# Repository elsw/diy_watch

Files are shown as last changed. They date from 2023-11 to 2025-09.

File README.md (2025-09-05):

# binary_watch

This is a project to create a homecrew binary watch to fit inside a analogue wrist watch

## issues

- No Vcc out of the LTC4071 chip, swapped LBSEL to set the `Low Battery Connect` to 3.6V but never get any voltage out. Change to MCP73833? also cheaper. [reference curcuit](https://learn.adafruit.com/li-ion-and-lipoly-batteries/downloads)
- Cannot debug RP2040 code, got it working once but not again, I think it's something up with the cdoe itself, debugging reliable blink code though... (change to pico 2??) (try embassy???)

## TODO

- Swap battery charger for MCP73833
- Recreate breadboard setup, test in rust
- Change PCB to 4 layer
- Change programming port for 3 pin JST SH (pico probe standard)
- Romove bool sel switch in favour of solder pads
- Swap LIR battery with space for lipo
- Add charging state LED

## Components
```
Cheap 6 digit LCD display
Raspberry Pi RP2040 Microchip
150mah lipo - https://thepihut.com/products/150mah-3-7v-lipo-battery
DS3231 real time clock
charging chip (breakout https://www.adafruit.com/product/259)
Standarise programming port on pico probe wire (1mm JST-SH, SM03B-SRSS-TB)
```

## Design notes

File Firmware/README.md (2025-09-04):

# DIY Watch firmware

This is the firmware for the DIY watch to run the raspberry pi RP2040 microcontroller

## References

[RP2040 Datasheet](https://datasheets.raspberrypi.com/rp2040/rp2040-datasheet.pdf)
[Raspberry Pi Pico C/C++ SDK](https://datasheets.raspberrypi.com/pico/raspberry-pi-pico-c-sdk.pdf)
[Driving multiplexed LCD directly](https://ww1.microchip.com/downloads/en/Appnotes/doc8103.pdf)

# Windows Setup

Install VS code and install the pico extension. Import this folder using the pico import tool.

I've had issues with linux, for pico 1 seems like windwso is easier, for pico2 linux might be fine

## Debugging

Grab a pre-compiled `debugprobe_on_pico.uf2` binary from [debug probe git](https://github.com/raspberrypi/debugprobe/releases)

Hold down BOOTSEL, connect your pico and drag and drop the binary.

The the USB drivers you may need to download [zadig](https://zadig.akeo.ie/)

If you have the right version it should appear as a CMIS_DAP device

Select `Picoprobe (interface 2)` and set the USB driver to `WinUSB`

At time of writing I am using pico SDK version `v2.2.0` and pico debug probe `v2.2.3`

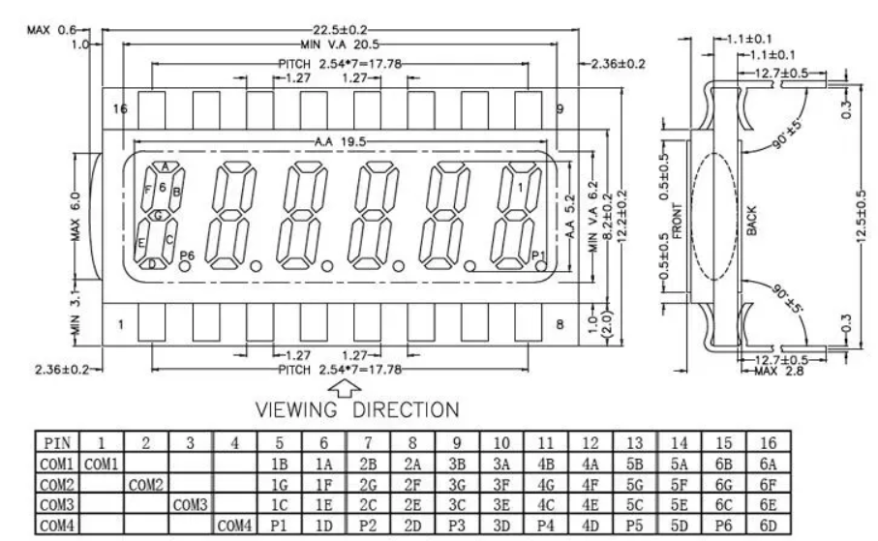
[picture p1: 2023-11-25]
Firmware/LCD_Panel.PNG

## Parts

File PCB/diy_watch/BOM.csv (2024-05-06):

Value | Reference | Footprint | JLCPCB Part | Part external | Qty | Link
Placed
1uF | C1, C4, C5, C6, C7, C8, C9 | Capacitor_SMD:C_0402_1005Metric | C52923 |  | 7 | https://jlcpcb.com/partdetail/53938-CL05A105KA5NQNC/C52923
20pF | C2, C3 | Capacitor_SMD:C_0402_1005Metric | C1554 |  | 2 | https://jlcpcb.com/partdetail/1906-0402CG200J500NT/C1554
1uf | C11 | Capacitor_SMD:C_0402_1005Metric | C52923 |  | 1 | https://jlcpcb.com/partdetail/53938-CL05A105KA5NQNC/C52923
LED | D1, D2, D3 | LED_SMD:LED_0805_2012Metric | C2296 |  | 3 | https://jlcpcb.com/partdetail/Hubei_KentoElec-KT0805Y/C2296
W25Q16JVUXIQ | IC1 | DIY_Watch_lib:SON50P300X200X60-9N | C2843335 |  | 1 | https://jlcpcb.com/partdetail/WinbondElec-W25Q16JVUXIQ/C2843335
1k | R1 | Resistor_SMD:R_0402_1005Metric | C11702 |  | 1 | https://jlcpcb.com/partdetail/12256-0402WGF1001TCE/C11702
5K | R3, R4, R5, R6, R7, R8, R9, R10 | Resistor_SMD:R_0402_1005Metric | C25900 |  | 8 | https://jlcpcb.com/partdetail/26643-0402WGF4701TCE/C25900
100K | R11 | Resistor_SMD:R_0402_1005Metric | C25741 |  | 1 | https://jlcpcb.com/partdetail/26484-0402WGF1003TCE/C25741
300 | R12, R13, R14 | Resistor_SMD:R_0402_1005Metric | C25104 |  | 3 | https://jlcpcb.com/partdetail/25847-0402WGF3300TCE/C25104
162 | R16 | Resistor_SMD:R_0402_1005Metric | C25091 |  | 1 | https://jlcpcb.com/parts/2nd/Resistors/Chip_Resistor_Surface_Mount_4?searchTxt=0402
DS3231MZ | U2 | Package_SO:SOIC-8_3.9x4.9mm_P1.27mm | C107410 |  | 1 | https://jlcpcb.com/partdetail/108629-DS3231MZTRL/C107410
RP2040 | U3 | Package_DFN_QFN:QFN-56-1EP_7x7mm_P0.4mm_EP3.2x3.2mm | C2040 |  | 1 | https://jlcpcb.com/partdetail/RaspberryPi-RP2040/C2040
XC6210B332MR | U7 | Package_TO_SOT_SMD:SOT-23-5 | C47719 |  | 1 | https://jlcpcb.com/partdetail/TorexSemicon-XC6210B332MRG/C47719
12MHz_crystal | Y1 | Crystal:Crystal_SMD_3225-4Pin_3.2x2.5mm | C9002 |  | 1 | https://jlcpcb.com/partdetail/Yxc-X322512MSB4SI/C9002
Manual
USB_B_Micro | J1 | Connector_USB:USB_Micro-B_GCT_USB3076-30-A |  | USB3076-30-A | 1 | https://www.mouser.co.uk/ProductDetail/GCT/USB3076-30-A?qs=KUoIvG%2F9IlZs3NcnVJVajg%3D%3D
LTC4071EMS8E_PBF | U8 | Package_SO:MSOP-8-1EP_3x3mm_P0.65mm_EP1.5x1.8mm |  |  | 1 | https://www.mouser.co.uk/ProductDetail/Analog-Devices/LTC4071EMS8EPBF?qs=hVkxg5c3xu%2F8j8%2Fv0cfFgA%3D%3D
~ | U6 | Diptronics FTE-2CA-V-T/R |  |  | 1 | https://www.mouser.co.uk/ProductDetail/CK/SDS001RULC?qs=vvQtp7zwQdNHkET%252Bn2UvUA%3D%3D
Battery_Cell | BT1 | Battery:BatteryHolder_Multicomp_BC-2001_1x2032 |  |  | 1 | https://www.mouser.co.uk/ProductDetail/TE-Connectivity-Linx-Technologies/BAT-HLD-001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
SW_Push | SW1 | Button_Switch_SMD:SW_SPST_EVQP7C |  |  | 1 | https://www.mouser.co.uk/ProductDetail/Panasonic/EVQ-P7C01P?qs=tfZGHB2PWd3p60%252BRGfXz%252Bg%3D%3D
~ | U4 | DIY_Watch_lib:6Dig7SegLCD |  |  | 1 | https://www.aliexpress.com/item/32324866141.html

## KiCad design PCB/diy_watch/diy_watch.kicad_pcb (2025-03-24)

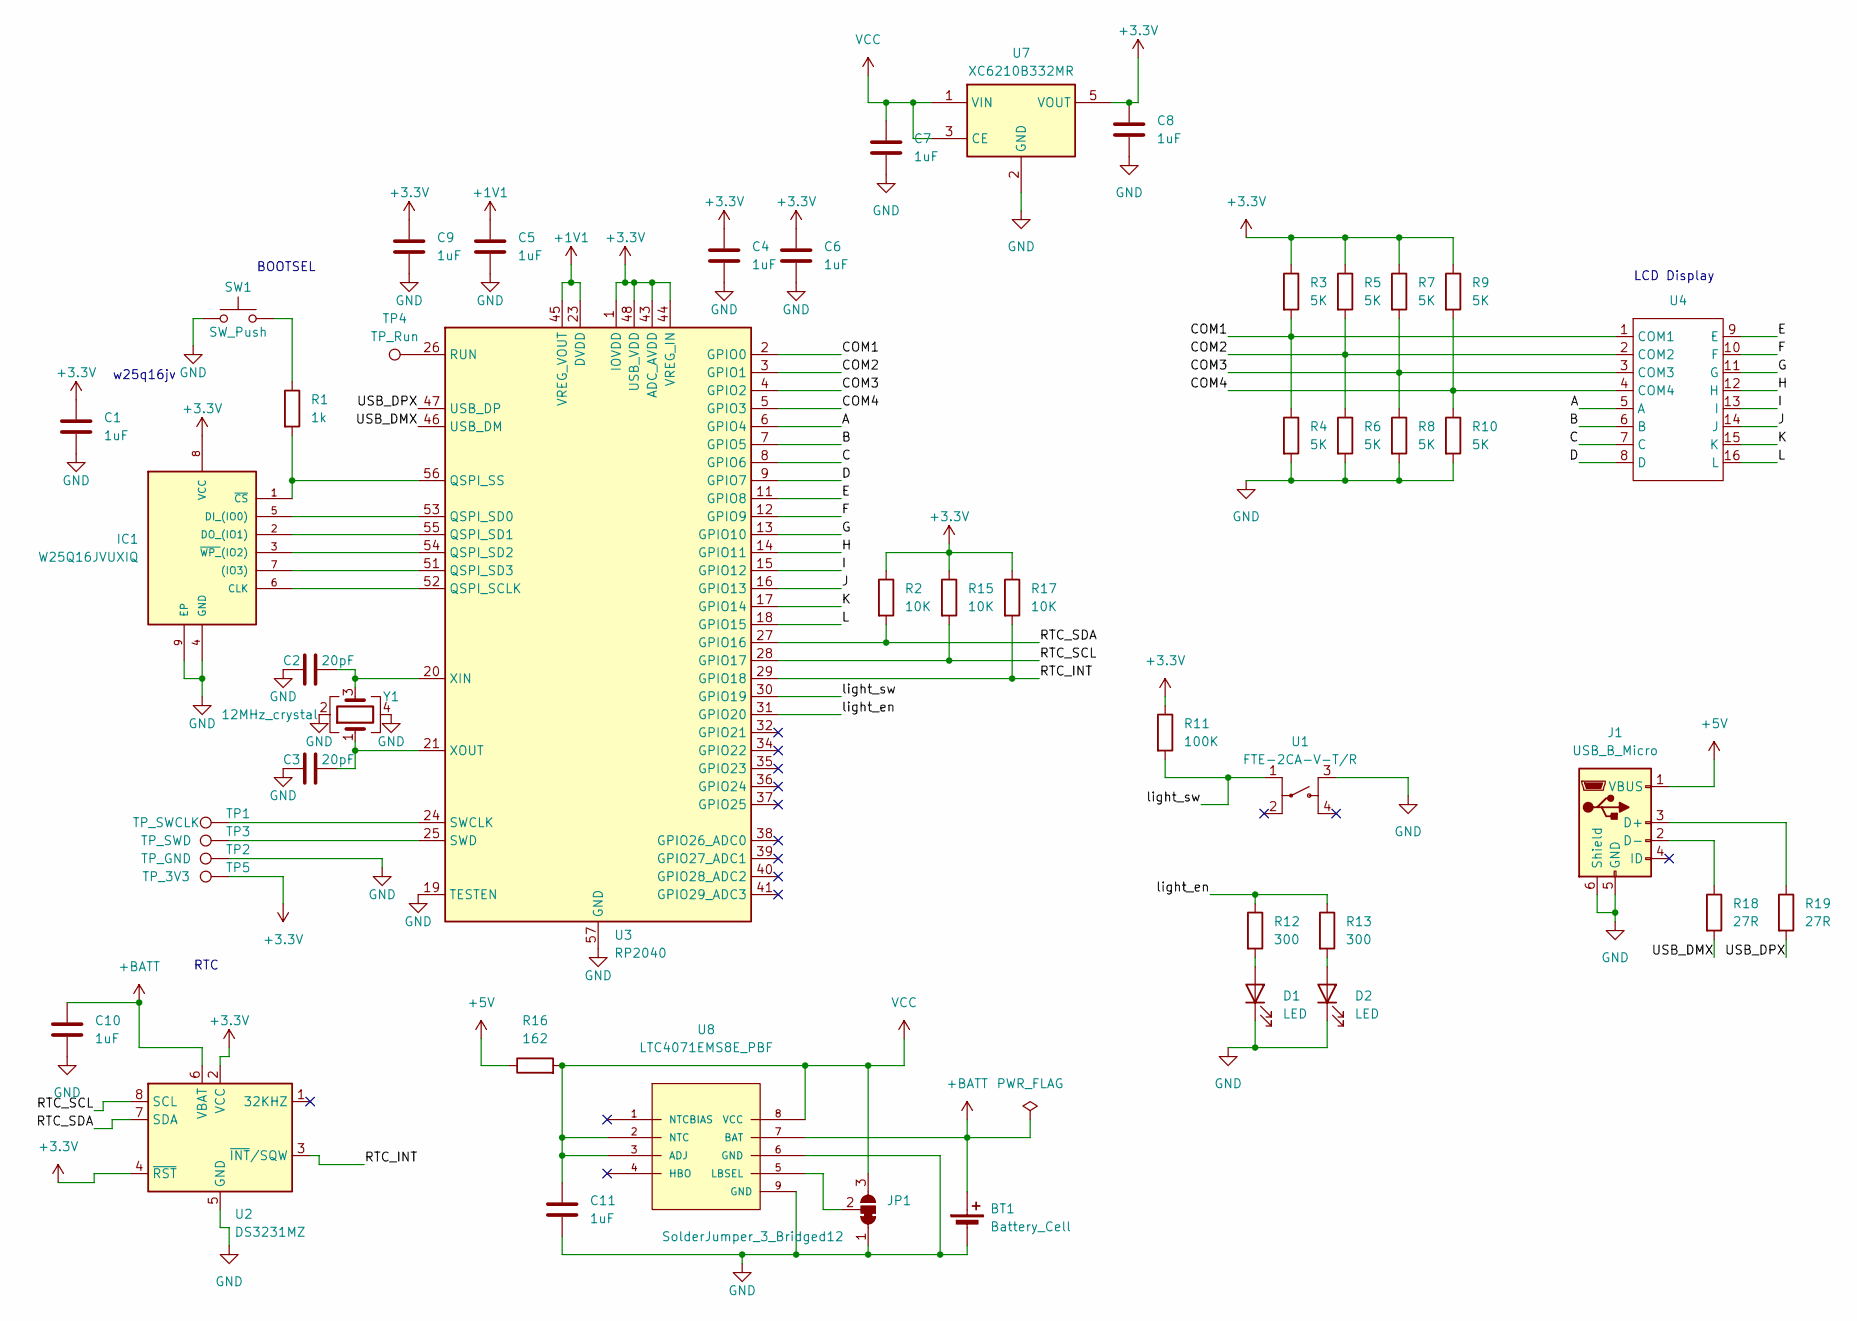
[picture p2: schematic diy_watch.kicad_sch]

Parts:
BT1: Battery_Cell; BatteryHolder_Multicomp_BC-2001_1x2032
C1, C4, C5, C6, C7, C8, C9, C10, C11: 1uF; C_0402_1005Metric; JLCPCB Part C52923
C2, C3: 20pF; C_0402_1005Metric; JLCPCB Part C1554
D1, D2: LED; LED_0805_2012Metric; JLCPCB Part C2296
IC1: W25Q16JVUXIQ; SON50P300X200X60-9N; MANUFACTURER_PART_NUMBER W25Q16JVUXIQ; JLCPCB Part C2843335
J1: USB_B_Micro; USB_Micro-B_GCT_USB3076-30-A
JP1: SolderJumper_3_Bridged12; SolderJumper-3_P1.3mm_Bridged12_RoundedPad1.0x1.5mm
R1: 1k; R_0402_1005Metric; JLCPCB Part C11702
R2, R15, R17: 10K; R_0402_1005Metric; JLCPCB Part C25744
R3, R4, R5, R6, R7, R8, R9, R10: 5K; R_0402_1005Metric; JLCPCB Part C25900
R11: 100K; R_0402_1005Metric; JLCPCB Part C25741
R12: 300; R_0402_1005Metric; JLCPCB Part C25104
R13: 300; LED_0402_1005Metric; JLCPCB Part C25104
R16: 162; R_0402_1005Metric; JLCPCB Part C25091
R18, R19: 27R; R_0402_1005Metric; JLCPCB Part C25100
SW1: SW_Push; SW_SPST_EVQP7C
TP1: TP_SWCLK; TestPoint_Pad_D1.5mm
TP2: TP_GND; TestPoint_Pad_D1.5mm
TP3: TP_SWD; TestPoint_Pad_D1.5mm
TP4: TP_Run; TestPoint_Pad_D1.0mm
TP5: TP_3V3; TestPoint_Pad_D1.5mm
U1: FTE-2CA-V-T/R; Diptronics FTE-3
U2: DS3231MZ; SOIC-8_3.9x4.9mm_P1.27mm; JLCPCB Part C107410
U3: RP2040; QFN-56-1EP_7x7mm_P0.4mm_EP3.2x3.2mm; JLCPCB Part C2040
U4: 6Dig7SegLCD
U7: XC6210B332MR; SOT-23-5; JLCPCB Part C47719
U8: LTC4071EMS8E_PBF; MSOP-8-1EP_3x3mm_P0.65mm_EP1.95x2.15mm; MANUFACTURER_PART_NUMBER ltc4071ems8e#pbf
Y1: 12MHz_crystal; Crystal_SMD_3225-4Pin_3.2x2.5mm; JLCPCB Part C9002

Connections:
+1V1: C5.1, U3.23 (DVDD), U3.45 (VREG_VOUT), U3.50 (DVDD)
+3.3V: C1.1, C4.1, C6.1, C8.1, C9.1, IC1.8 (VCC), R2.1, R3.1, R5.1, R7.1, R9.1, R11.1, R15.1, R17.1, TP5.1, U2.2 (VCC), U2.4 (~RST), U3.1 (IOVDD), U3.10 (IOVDD), U3.22 (IOVDD), U3.33 (IOVDD), U3.42 (IOVDD), U3.43 (ADC_AVDD), U3.44 (VREG_IN), U3.48 (USB_VDD), U3.49 (IOVDD), U7.5 (VOUT)
+5V: J1.1 (VBUS), R16.1
+BATT: BT1.1 (+), C10.1, U2.6 (VBAT), U8.7 (BAT)
/A: U3.6 (GPIO4), U4.5 (A)
/B: U3.7 (GPIO5), U4.6 (B)
/C: U3.8 (GPIO6), U4.7 (C)
/COM1: R3.2, R4.1, U3.2 (GPIO0), U4.1 (COM1)
/COM2: R5.2, R6.1, U3.3 (GPIO1), U4.2 (COM2)
/COM3: R7.2, R8.1, U3.4 (GPIO2), U4.3 (COM3)
/COM4: R9.2, R10.1, U3.5 (GPIO3), U4.4 (COM4)
/D: U3.9 (GPIO7), U4.8 (D)
/E: U3.11 (GPIO8), U4.9 (E)
/F: U3.12 (GPIO9), U4.10 (F)
/G: U3.13 (GPIO10), U4.11 (G)
/H: U3.14 (GPIO11), U4.12 (H)
/I: U3.15 (GPIO12), U4.13 (I)
/J: U3.16 (GPIO13), U4.14 (J)
/K: U3.17 (GPIO14), U4.15 (K)
/L: U3.18 (GPIO15), U4.16 (L)
/RTC_INT: R17.2, U2.3 (~INT/SQW), U3.29 (GPIO18)
/RTC_SCL: R15.2, U2.8 (SCL), U3.28 (GPIO17)
/RTC_SDA: R2.2, U2.7 (SDA), U3.27 (GPIO16)
/USB_DMX: R18.2, U3.46 (USB_DM)
/USB_DPX: R19.2, U3.47 (USB_DP)
/light_en: R12.1, R13.1, U3.31 (GPIO20)
/light_sw: R11.2, U1.1, U3.30 (GPIO19)
GND: BT1.2 (-), C1.2, C2.1, C3.1, C4.2, C5.2, C6.2, C7.2, C8.2, C9.2, C10.2, C11.2, D1.1 (K), D2.1 (K), IC1.4 (GND), IC1.9 (EP), J1.5 (GND), J1.6 (Shield), JP1.1 (A), R4.2, R6.2, R8.2, R10.2, SW1.1, TP2.1, U1.3, U2.5 (GND), U3.19 (TESTEN), U3.57 (GND), U7.2 (GND), U8.6 (GND), U8.9 (GND), Y1.2, Y1.4
unnamed: D1.2 (A), R12.2
unnamed: D2.2 (A), R13.2
unnamed: IC1.7 ((IO3)), U3.51 (QSPI_SD3)
unnamed: IC1.6 (CLK), U3.52 (QSPI_SCLK)
unnamed: IC1.5 (DI_(IO0)), U3.53 (QSPI_SD0)
unnamed: IC1.2 (DO_(IO1)), U3.55 (QSPI_SD1)
unnamed: IC1.1 (~CS), R1.2, U3.56 (QSPI_SS)
unnamed: IC1.3 (~WP_(IO2)), U3.54 (QSPI_SD2)
unnamed: J1.3 (D+), R19.1
unnamed: J1.2 (D-), R18.1
unnamed: JP1.2 (C), U8.5 (LBSEL)
unnamed: R1.1, SW1.2
unnamed: TP4.1, U3.26 (RUN)
unnamed: TP1.1, U3.24 (SWCLK)
unnamed: TP3.1, U3.25 (SWD)
unnamed: C2.2, U3.20 (XIN), Y1.3
unnamed: C3.2, U3.21 (XOUT), Y1.1
VCC: C7.1, C11.1, JP1.3 (B), R16.2, U7.1 (VIN), U7.3 (CE), U8.2 (NTC), U8.3 (ADJ), U8.8 (VCC)

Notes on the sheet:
RTC
w25q16jv
BOOTSEL
LCD Display

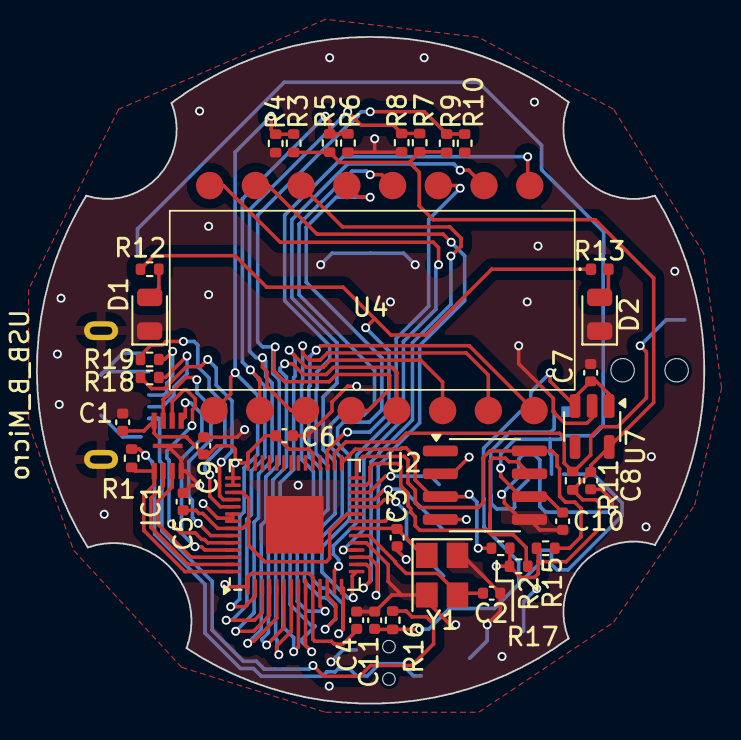
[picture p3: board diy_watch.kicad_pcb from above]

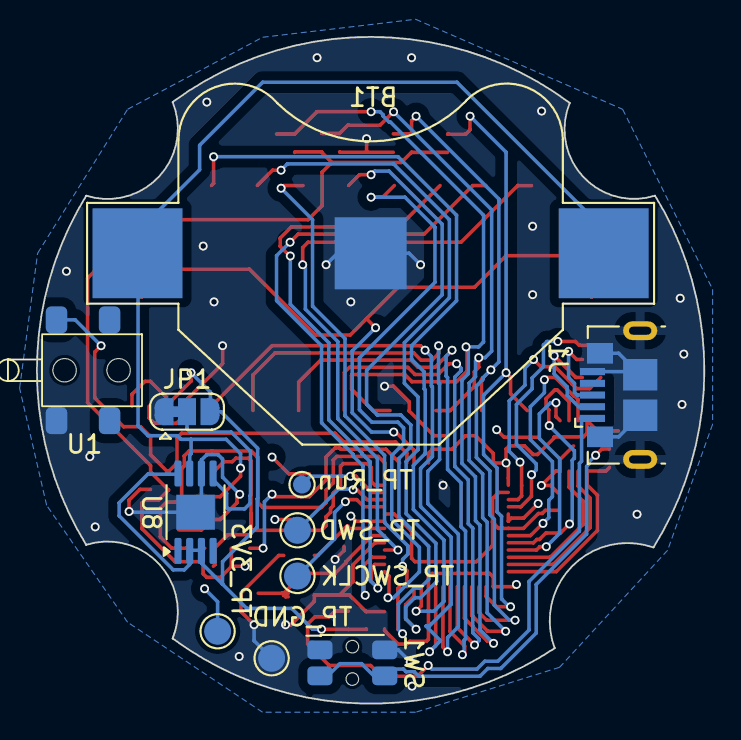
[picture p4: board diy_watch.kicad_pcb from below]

Board: 4 copper layers, 37.1 x 37.0 mm, 48 parts (11 on the bottom side), 46 nets.

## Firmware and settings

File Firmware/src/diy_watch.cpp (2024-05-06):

#include "pico/stdlib.h"
#include "hardware/pio.h"
#include "hardware/i2c.h"
#include "multiplex_lcd.pio.h"
#include "diy_watch/multiplex_lcd_drv.h"
#include "diy_watch/RTClib.h"
#include "diy_watch/usb_serial.h"
#include <iostream>
#include <stdio.h>

const uint LED_PIN = PICO_DEFAULT_LED_PIN;
const uint RTC_1HZ_PIN = 18;

const uint LCD_BASE_PIN = 0;
const uint LCD_SM = 1; //LCD State Machine
const uint TARGET_LCD_CYCLE_HZ = 250; //4ms per cycle, 4 cycles per refresh

MultiplexLCDDriver::Ptr lcd;
unsigned seconds = 0;
unsigned minutes = 0;
unsigned hours = 0;

void pio_irh() 
{
  lcd->FIFOEmpty();
  pio0_hw->irq = 1;
}

void gpio_callback(uint gpio, uint32_t events) 
{
    if(gpio==RTC_1HZ_PIN)
    {
        //Increment time
        gpio_put(LED_PIN,!gpio_get(LED_PIN));
        uint8_t digits[6];
        seconds++;
        if(seconds > 59)
        {
          minutes++;
          seconds = 0;
          if(minutes > 59)
          {
            hours++;
            minutes = 0;
            if(hours > 24)
            {
              hours = 0;
            }
          }
        }
        digits[0] = seconds % 10;
        digits[1] = seconds / 10;
        digits[2] = minutes % 10;
        digits[3] = minutes / 10;
        digits[4] = hours % 10;
        digits[5] = hours / 10;

        lcd->UpdateOutput(digits);
    }
}

int main()
{
    gpio_init(LED_PIN);
    gpio_set_dir(LED_PIN, GPIO_OUT);

    //Init LCD PIO Driver
    PIO pio = pio0;
    //Load program into memory
    uint offset = pio_add_program(pio, &multiplex_lcd_drv_program);
    //Claim state machine
    pio_sm_claim(pio, LCD_SM);
    //Initialise driver
    lcd = std::make_shared<MultiplexLCDDriver>(pio,LCD_SM,offset,LCD_BASE_PIN,TARGET_LCD_CYCLE_HZ);

    gpio_init(RTC_1HZ_PIN);
    gpio_set_dir(RTC_1HZ_PIN, GPIO_IN);
    gpio_set_irq_enabled_with_callback(RTC_1HZ_PIN, GPIO_IRQ_EDGE_RISE, true, &gpio_callback);

    // Enable IRQ0 on PIO0
    irq_set_exclusive_handler(PIO0_IRQ_0, pio_irh);
    pio0_hw->inte0 = PIO_IRQ0_INTE_SM0_BITS;

    //sm_config_set_mov_status (&c, STATUS_TX_LESSTHAN , 1 )

    //Enable IRQ from LCD PIO code
    irq_set_enabled(PIO0_IRQ_0, true);
    pio_sm_put(pio0,LCD_SM,0x00000000);

    RTC_DS3231 rtc;
    rtc.writeSqwPinMode(Ds3231SqwPinMode::DS3231_SquareWave1Hz);

    //check the setting has taken
    Ds3231SqwPinMode mode = rtc.readSqwPinMode();
    std::cout << "DIY Watch v " << static_cast<int>(mode) << std::endl;

    diy_watch::USBSerial usb;

    while (true) 
    {
      bool got_time_update = usb.update();
      if(got_time_update)
      {
        diy_watch::Time time = usb.getTime();
        seconds = time.seconds;
        minutes = time.minutes;
        hours = time.hours;
      }

      //sleep_ms(1000);
      //gpio_callback(RTC_1HZ_PIN, 0) ;
    }
}

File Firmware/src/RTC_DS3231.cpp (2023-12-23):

#include "diy_watch/RTClib.h"
#include "hardware/i2c.h"
#include "pico/stdlib.h"

constexpr uint8_t DS3231_ADDRESS = 0x68;   ///< I2C address for DS3231
constexpr uint8_t DS3231_TIME = 0x00;      ///< Time register
constexpr uint8_t DS3231_ALARM1 = 0x07;    ///< Alarm 1 register
constexpr uint8_t DS3231_ALARM2 = 0x0B;    ///< Alarm 2 register
constexpr uint8_t DS3231_CONTROL = 0x0E;   ///< Control register
constexpr uint8_t DS3231_STATUSREG = 0x0F; ///< Status register
constexpr uint8_t DS3231_TEMPERATUREREG = 0x11; ///< Temperature register (high byte - low byte is at 0x12), 10-bit
constexpr uint sda_pin = 16;
constexpr uint scl_pin = 17;
constexpr i2c_inst_t * i2c_port = i2c0;

RTC_DS3231::RTC_DS3231()
{
  address = DS3231_ADDRESS;
  //Setup pins for I2C
  gpio_set_function(sda_pin, GPIO_FUNC_I2C);
  gpio_set_function(scl_pin, GPIO_FUNC_I2C);

  i2c_dev = i2c_port;
  //Initialize I2C port at 400 kHz
  i2c_init(i2c_dev, 400 * 1000);
}

/**************************************************************************/
/*!
    @brief  Start I2C for the DS3231 and test succesful connection
    @param  wireInstance pointer to the I2C bus
    @return True if Wire can find DS3231 or false otherwise.
*/
/**************************************************************************/
/*void RTC_DS3231::begin(i2c_inst_t *i2c) {
  i2c_dev = i2c;
}*/

/**************************************************************************/
/*!
    @brief  Check the status register Oscillator Stop Flag to see if the DS3231
   stopped due to power loss
    @return True if the bit is set (oscillator stopped) or false if it is
   running
*/
/**************************************************************************/
bool RTC_DS3231::lostPower(void) {
  return read_register(DS3231_STATUSREG) >> 7;
}

/**************************************************************************/
/*!
    @brief  Set the date and flip the Oscillator Stop Flag
    @param dt DateTime object containing the date/time to set
*/
/**************************************************************************/
/*void RTC_DS3231::adjust(const DateTime &dt) {
  uint8_t buffer[8] = {DS3231_TIME,
                       bin2bcd(dt.second()),
                       bin2bcd(dt.minute()),
                       bin2bcd(dt.hour()),
                       bin2bcd(dowToDS3231(dt.dayOfTheWeek())),
                       bin2bcd(dt.day()),
                       bin2bcd(dt.month()),
                       bin2bcd(dt.year() - 2000U)};
  i2c_dev->write(buffer, 8);

  uint8_t statreg = read_register(DS3231_STATUSREG);
  statreg &= ~0x80; // flip OSF bit
  write_register(DS3231_STATUSREG, statreg);
}*/

/**************************************************************************/
/*!
    @brief  Get the current date/time
    @return DateTime object with the current date/time
*/
/**************************************************************************/
/*DateTime RTC_DS3231::now() {
  uint8_t buffer[7];
  buffer[0] = 0;
  i2c_dev->write_then_read(buffer, 1, buffer, 7);

  return DateTime(bcd2bin(buffer[6]) + 2000U, bcd2bin(buffer[5] & 0x7F),
                  bcd2bin(buffer[4]), bcd2bin(buffer[2]), bcd2bin(buffer[1]),
                  bcd2bin(buffer[0] & 0x7F));
}*/

/**************************************************************************/
/*!
    @brief  Read the SQW pin mode
    @return Pin mode, see Ds3231SqwPinMode enum
*/
/**************************************************************************/
Ds3231SqwPinMode RTC_DS3231::readSqwPinMode() {
  int mode;
  mode = read_register(DS3231_CONTROL) & 0x1C;
  if (mode & 0x04)
    mode = DS3231_OFF;
  return static_cast<Ds3231SqwPinMode>(mode);
}

/**************************************************************************/
/*!
    @brief  Set the SQW pin mode
    @param mode Desired mode, see Ds3231SqwPinMode enum
*/
/**************************************************************************/
void RTC_DS3231::writeSqwPinMode(Ds3231SqwPinMode mode) {
  uint8_t ctrl = read_register(DS3231_CONTROL);

  ctrl &= ~0x04; // turn off INTCON
  ctrl &= ~0x18; // set freq bits to 0

  write_register(DS3231_CONTROL, ctrl | mode);
}

/**************************************************************************/
/*!
    @brief  Get the current temperature from the DS3231's temperature sensor
    @return Current temperature (float)
*/
/**************************************************************************/
/*float RTC_DS3231::getTemperature() {
  uint8_t buffer[2] = {DS3231_TEMPERATUREREG, 0};
  i2c_dev->write_then_read(buffer, 1, buffer, 2);
  return (float)buffer[0] + (buffer[1] >> 6) * 0.25f;
}*/

/**************************************************************************/
/*!
    @brief  Set alarm 1 for DS3231
        @param 	dt DateTime object
        @param 	alarm_mode Desired mode, see Ds3231Alarm1Mode enum
    @return False if control register is not set, otherwise true
*/
/**************************************************************************/
/*bool RTC_DS3231::setAlarm1(const DateTime &dt, Ds3231Alarm1Mode alarm_mode) {
  uint8_t ctrl = read_register(DS3231_CONTROL);
  if (!(ctrl & 0x04)) {
    return false;
  }

  uint8_t A1M1 = (alarm_mode & 0x01) << 7; // Seconds bit 7.
  uint8_t A1M2 = (alarm_mode & 0x02) << 6; // Minutes bit 7.
  uint8_t A1M3 = (alarm_mode & 0x04) << 5; // Hour bit 7.
  uint8_t A1M4 = (alarm_mode & 0x08) << 4; // Day/Date bit 7.
  uint8_t DY_DT = (alarm_mode & 0x10)
                  << 2; // Day/Date bit 6. Date when 0, day of week when 1.
  uint8_t day = (DY_DT) ? dowToDS3231(dt.dayOfTheWeek()) : dt.day();

  uint8_t buffer[5] = {DS3231_ALARM1, uint8_t(bin2bcd(dt.second()) | A1M1),
                       uint8_t(bin2bcd(dt.minute()) | A1M2),
                       uint8_t(bin2bcd(dt.hour()) | A1M3),
                       uint8_t(bin2bcd(day) | A1M4 | DY_DT)};
  i2c_dev->write(buffer, 5);

  write_register(DS3231_CONTROL, ctrl | 0x01); // AI1E

  return true;
}*/
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

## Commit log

2023-11-18 Added PCB initial start
    [binary_watch.kicad_pcb, binary_watch.kicad_sch]
2023-11-19 Changed to use 7seg display, removing wireless charging
    [binary_watch.kicad_pcb, binary_watch.kicad_sch, diy_watch.kicad_pcb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]
2023-11-21 Adding datasheets
    [diy_watch.kicad_sch]
2023-11-22 Added self contained test program for pico Added README for setup in WSL
2023-11-23 Starting PIO driver to simplify lcd
2023-11-25 Adding LCD driver functionality Added LCD pinout picture
2023-12-06 Updating LCD driver Updated RTC pinout
    [diy_watch.kicad_sch]
2023-12-13 Refactoring LCD driver
2023-12-14 Fixed lcd driver inverted signals
2023-12-14 Fixed LCD digit matrix fixed LCD pin counts
    [diy_watch.cpp]
2023-12-23 Adding USB serial communication Added python script to send time to the watch Moved i2c code to rtc constructor Added time counting to LCD
2023-12-23 Updating watch PCB
    Added COM resistor pullup/downs
    Added switch
    Added LEDs
    [diy_watch.kicad_pcb, diy_watch.kicad_sch]
2023-12-23 Updated swich layout and symbol
    [diy_watch.kicad_pcb, diy_watch.kicad_sch]
2023-12-26 Routed most of the PCB, big staggetti
    [diy_watch.kicad_pcb, diy_watch.kicad_sch]
2023-12-27 Finished wiring, not started on DRC errors
    [diy_watch.kicad_pcb]
2023-12-27 Added caps to regulator, Changed edge cut
    Adding missing pullup on switch
    [diy_watch.kicad_pcb, diy_watch.kicad_sch]
2023-12-27 Updated silkscreen names
    [diy_watch.kicad_pcb, diy_watch.kicad_sch]
2024-01-03 Removed wires and Rearranged PCB layout to create more space
    [diy_watch.kicad_pcb, diy_watch.kicad_sch]
2024-01-06 Changed charging chip and flash chip, rearranged parts
    [diy_watch.kicad_pcb, diy_watch.kicad_sch]
2024-01-07 Re-routed refactored board
    [diy_watch.kicad_pcb, diy_watch.kicad_sch]
2024-01-07 Fixing DRC errors on PCB
    [diy_watch.kicad_pcb, diy_watch.kicad_sch]
2024-01-18 Adding BOM
    [BOM.csv, diy_watch.kicad_pcb, diy_watch.kicad_sch]
2024-01-18 Updating components for stock reasons
    [BOM.csv, diy_watch.kicad_pcb, diy_watch.kicad_sch]
2024-05-06 Adding fixes to PCB schematic
    [BOM.csv, diy_watch.kicad_sch]
2025-02-19 Updating to 4 layer board Adding missing caps to schematic Updating pcb with schematic fixes
    [diy_watch.kicad_pcb, diy_watch.kicad_sch]
2025-02-19 Added more PCB tracks
    [diy_watch.kicad_pcb]
2025-02-20 Refactored layer setup to be more efficient
    [diy_watch.kicad_pcb]
2025-02-20 More routing on new 4 layer stack
    [diy_watch.kicad_pcb]
2025-02-20 Fixing ERC and DRC errors
    [diy_watch.kicad_pcb, diy_watch.kicad_sch]
2025-02-25 Fixing DRC warnings
    [diy_watch.kicad_pcb, diy_watch.kicad_sch]
2025-02-25 Added mounting piont cutouts to PCB
    [diy_watch.kicad_pcb]
2025-02-25 Rerouted with new spaces for back mounting
    [diy_watch.kicad_pcb]
2025-02-26 More DRC corrections
    [diy_watch.kicad_pcb]
2025-02-26 DRC Fixes
    [diy_watch.kicad_pcb]
2025-02-27 More DRC fixes
    [diy_watch.kicad_pcb, diy_watch.kicad_sch]
2025-03-05 Adding JLC part numbers to schematic
    [diy_watch.kicad_pcb, diy_watch.kicad_sch]
